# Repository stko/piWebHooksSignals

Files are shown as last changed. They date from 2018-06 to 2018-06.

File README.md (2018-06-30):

# piWebHooksSignals & PiPowerOff
## Introduction

This application do two things
- the hardware provides a complete power on/off system, where the raspi can be powered by a battery powerpack and turns himself off after finishing his job. In off state the battery is completely disconnected, so there's no quiescent current which could drain the battery.
 - the software deamon  manages the LEDs and the poweroff. It's controlled by ascii commands received on port 3000.

## Details
The hardware power on is triggered by a short press on the button. When the raspi is going into power off state at the end, it pulls GPIO pin 22 to HIGH, which switches the hardware power off again. (In case of emergency, a longer press also switches the power off)
The sample application reads the `webhooks.cfg` and tries to fire all found webhooks out of the config, while it send ASCII status commands via TCP port 3000 to the LED & power control task. At the end the command EXIT makes the system to power off.

## Install

To install piWebHooksSignals, get a virgin raspian lite image from raspberry.org (tested on raspian stretch)
boot the virgin raspian image, login
start the install script with

    bash <(curl -s https://raw.githubusercontent.com/stko/piWebHooksSignals/master/install.sh)

the installation will take appr. 20 minutes.

After the installation you should adjust your settings before reboot, because after that your file system will be read only (which you can temporarily change with `sudo mount -o remount,rw /` then)

In case of the sample application, the settings would be the UMTS stick settings in `/etc/wvdial.conf` and the web hooks to call in `/etc/piWebHooksSignals/webhooks.cfg`

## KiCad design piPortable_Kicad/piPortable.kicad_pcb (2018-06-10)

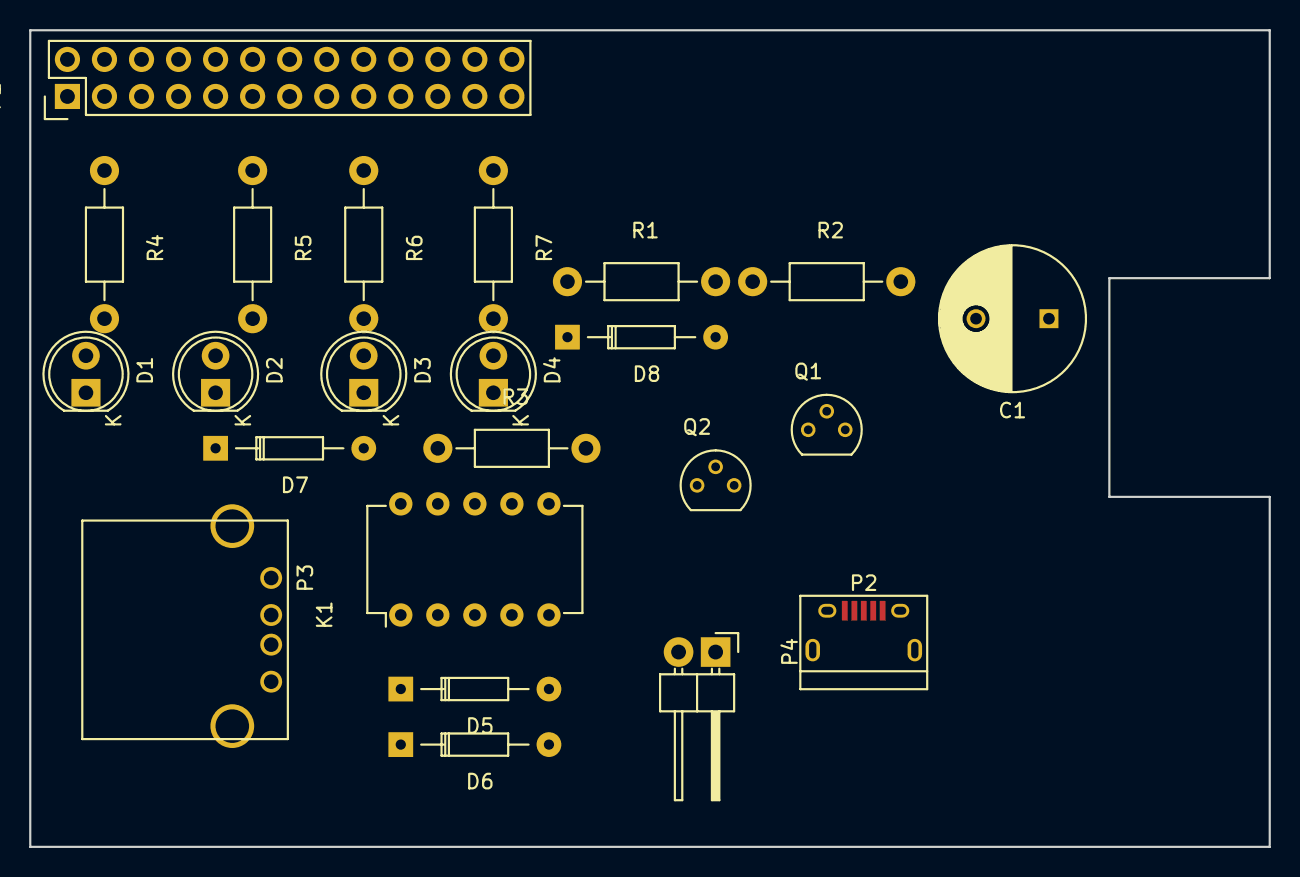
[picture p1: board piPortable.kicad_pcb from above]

Board: 2 copper layers, 85.0 x 56.0 mm, 23 parts (0 on the bottom side), 17 nets, no tracks yet.

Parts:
C1: CP_Small; C_Radial_D10_L13_P5
D1: Power; LED-5MM
D2: Green; LED-5MM
D3: Yellow; LED-5MM
D4: Red; LED-5MM
D5, D6, D7, D8: D4148; Diode_DO-35_SOD27_Horizontal_RM10
K1: G6S-2; DIP-10_W7.62mm
P1: CONN_13X2; Pin_Header_Straight_2x13
P2: USB_OTG; USB_Micro-B
P3: USB_A
P4: CONN_02X01; Pin_Header_Angled_1x02
Q1, Q2: BC237; TO-92_Molded_Narrow
R1: 1M; Resistor_Horizontal_RM10mm
R2: 10M; Resistor_Horizontal_RM10mm
R3: 10K; Resistor_Horizontal_RM10mm
R4, R5, R6, R7: 330R; Resistor_Horizontal_RM10mm

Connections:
/GPIO17: P1.11, R5.1
/GPIO18: D8.2, P1.12
/GPIO21: P1.13, R6.1
/GPIO22: P1.15, R7.1
GND: C1.2, D1.1, D2.1, D3.1, D4.1, P1.6, P2.5, P2.6, P3.4, P3.5, Q1.3, Q2.3, R2.2
unnamed: C1.1, Q1.2, R1.2, R2.1
unnamed: D1.2, R4.2
unnamed: D2.2, R5.2
unnamed: D3.2, R6.2
unnamed: D4.2, R7.2
unnamed: D5.1, D6.1, K1.1, R3.1
unnamed: D5.2, K1.5, P3.1, R4.1
unnamed: D6.2, D7.2, P4.2
unnamed: D7.1, D8.1, R1.1
unnamed: K1.4, P2.1, P4.1
unnamed: K1.10, Q2.1
unnamed: Q1.1, Q2.2, R3.2

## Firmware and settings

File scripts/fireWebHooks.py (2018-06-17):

from __future__ import print_function
import sys
import requests
import json
import time

def eprint(*args, **kwargs):
	print(*args, file=sys.stderr, **kwargs)

def flushprint(*args, **kwargs):
	print(*args, file=sys.stdout, **kwargs)
	sys.stdout.flush()

with open(sys.argv[1]) as f:
	data = json.load(f)
msgID=0 # read GPIOs here later to select different msgs.
flushprint("ON")
time.sleep( 3 )
try:
	myCfg=data[msgID]
	flushprint("BYELLOW")
	try:
		for hook in myCfg:
			url=hook["url"]
			payload=hook["payload"]
			try:
				requests.post(url, data=payload)
				flushprint("GREEN")
			except:
				flushprint("RED")
				eprint("error sending request")
	except:
		flushprint("RED")
		eprint("format error in config array!")
except:
	flushprint("RED")
	eprint("id {0} not found in config array".format(msgID))
time.sleep( 5 )
flushprint("EXIT")

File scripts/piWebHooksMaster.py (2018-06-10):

from threading import Thread
from queue import Queue, Empty
import sys
import json
from gpiozero import LED

from time import sleep

from pprint import pprint

class NonBlockingStreamReader:

	def __init__(self, stream):
		'''
		stream: the stream to read from.
				Usually a process' stdout or stderr.
		'''

		self._s = stream
		self._q = Queue()

		def _populateQueue(stream, queue):
			'''
			Collect lines from 'stream' and put them in 'quque'.
			'''

			while True:
				line = stream.readline()
				if line:
					queue.put(line)
				else:
					raise UnexpectedEndOfStream

		self._t = Thread(target = _populateQueue,
				args = (self._s, self._q))
		self._t.daemon = True
		self._t.start() #start collecting lines from the stream

	def readline(self, timeout = None):
		try:
			return self._q.get(block = timeout is not None,
					timeout = timeout)
		except Empty:
			return None

class UnexpectedEndOfStream(Exception): pass

def updateLEDStates():
	global ledStates
	for idx, val in ledStates.items():
		if val["actstate"]>1:
			if val["actstate"]==2: # time to change the state..
				val["led"].toggle()
				val["actstate"]=val["state"]
			else:
				val["actstate"]-=1


def evalCmd(cmd):
	global data
	global ledStates
	try:
		for idx, val in enumerate(data["commands"][cmd]):
			if val==-1:
				continue
			ledStates[idx]["state"]=val
			ledStates[idx]["actstate"]=val
			if val>0:
				ledStates[idx]["led"].on()
			else:
				ledStates[idx]["led"].off()
	except: # command does not exist
		print ('Inknown command',cmd)
	
# wrap sys.stdin with a NonBlockingStreamReader object:
nbsr = NonBlockingStreamReader(sys.stdin)
# readConfig
with open(sys.argv[1]) as f:
    data = json.load(f)
pprint(data)
ledStates={}
for idx, val in enumerate(data["config"]):
  ledStates[idx]={}
  ledStates[idx]["led"]=LED(val)
  ledStates[idx]["state"]=0
  ledStates[idx]["actstate"]=0

evalCmd("INIT")
cmd=""
# get the cmd
while cmd!="EXIT":
	cmd = nbsr.readline(0.5) # 0.1 secs to let the shell cmd the result
	if cmd:
		cmd=cmd.upper().strip()
		print ("--",cmd)
		evalCmd(cmd)
	updateLEDStates()

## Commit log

2018-06-10 working on to make it work...
    [sample_leds.cfg]
2018-06-30 setup now without unison filesystem, seems to solve poweroff failure
